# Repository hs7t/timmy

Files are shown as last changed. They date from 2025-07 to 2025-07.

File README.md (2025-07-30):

# Timmy

Timmy is a small [hackpad](https://hackpad.hackclub.com/) input device!
It features:

- a custom PCB
- two fun knobs
- 9 keys
- a pretty cool case!

## Parts

Timmy is composed of a case and two knob caps, totaling four
3D-printed pieces (the case top and bottom, a round knob, and a square knob).
It took me a bit to arrive at this design, and I'm quite fond of
it! Everything fits together using heatset inserts for 4 M3 bolts.

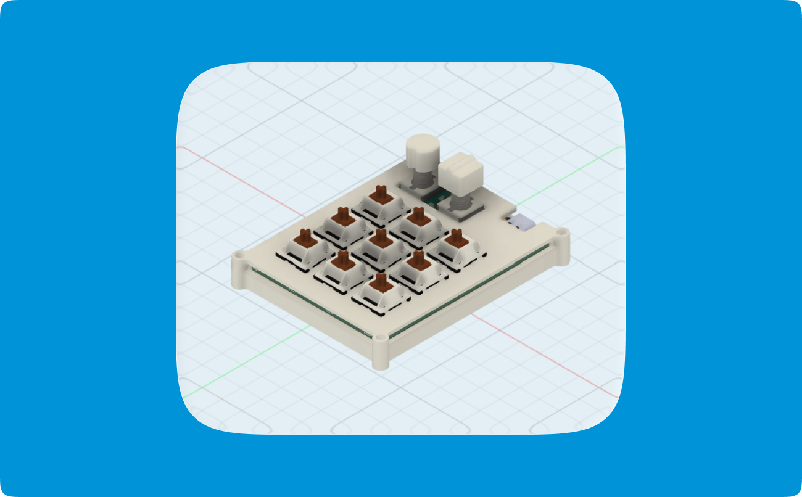
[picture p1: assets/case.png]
An angled top view of a macropad with 9 switches and two rotary encoders

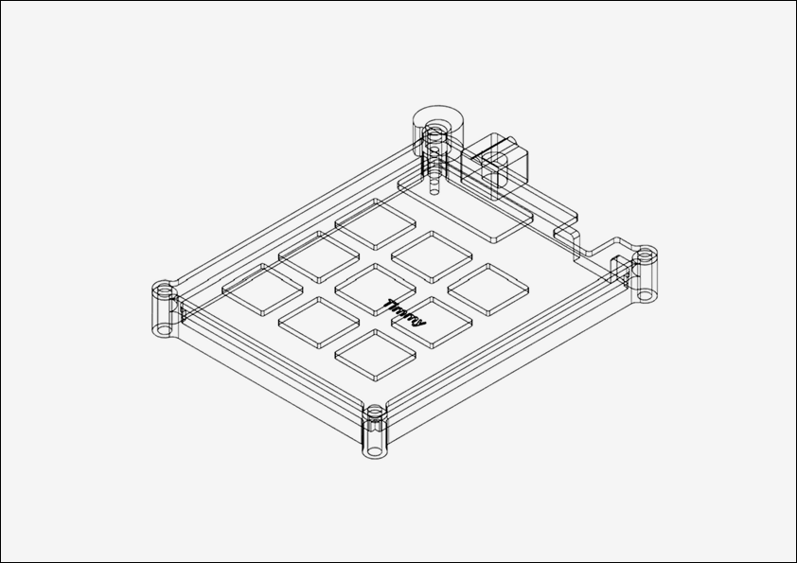
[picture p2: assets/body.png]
An angled top view of the macropad's body


## PCB

The PCB was designed in KiCAD. It's my first PCB ever, so it might
not be that great!

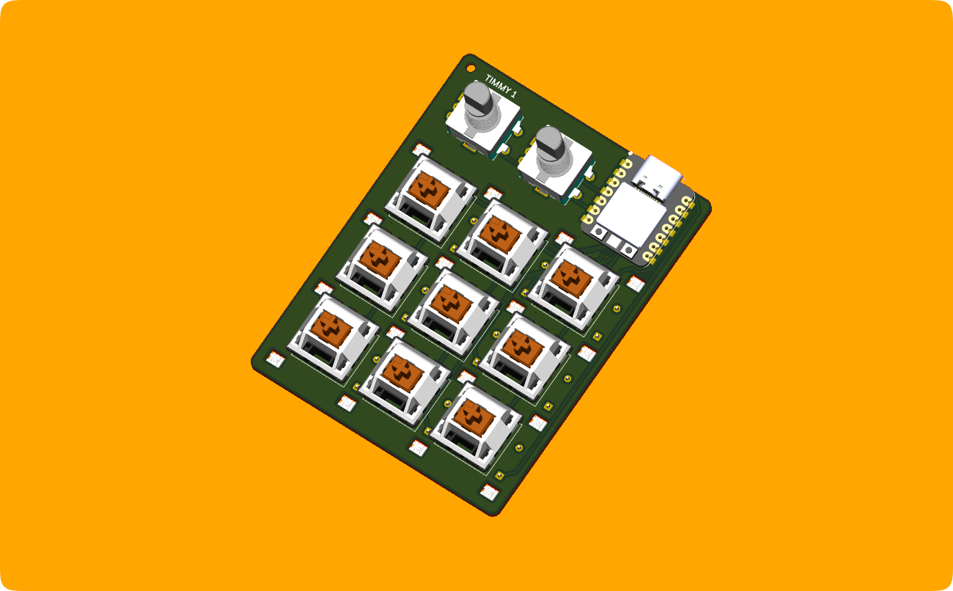
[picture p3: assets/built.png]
A render of PCB assembled with various components, including a microcontroller, two rotary encoders, and various switches

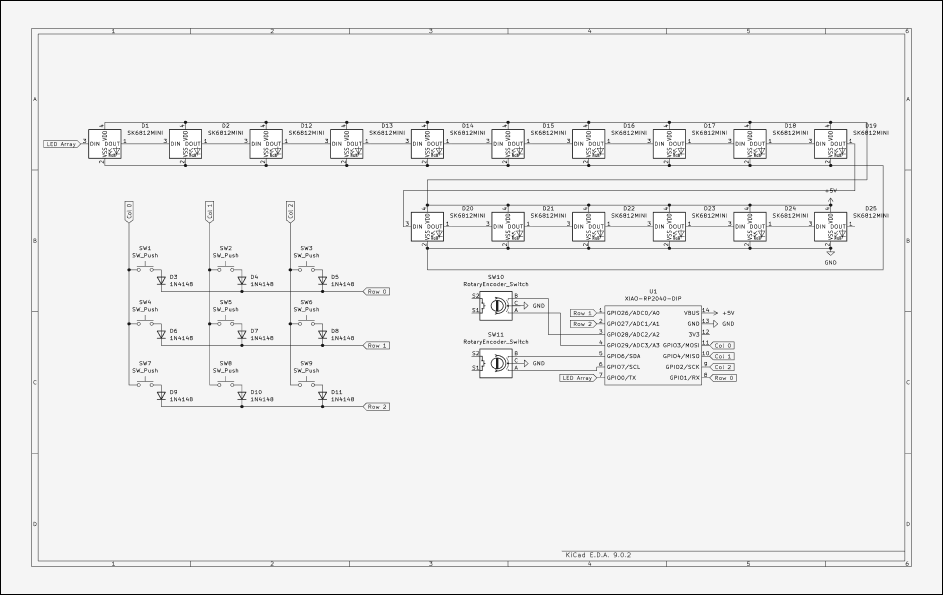
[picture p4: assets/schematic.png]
S screenshot of the schematic for the PCB


This board is double-layered and has a ground copper fill.

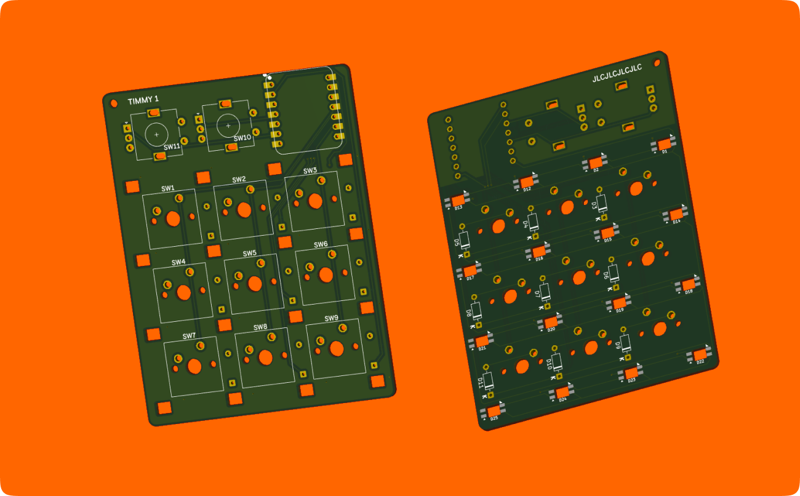
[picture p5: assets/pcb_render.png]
Renders for the PCB without components from front and behind angles

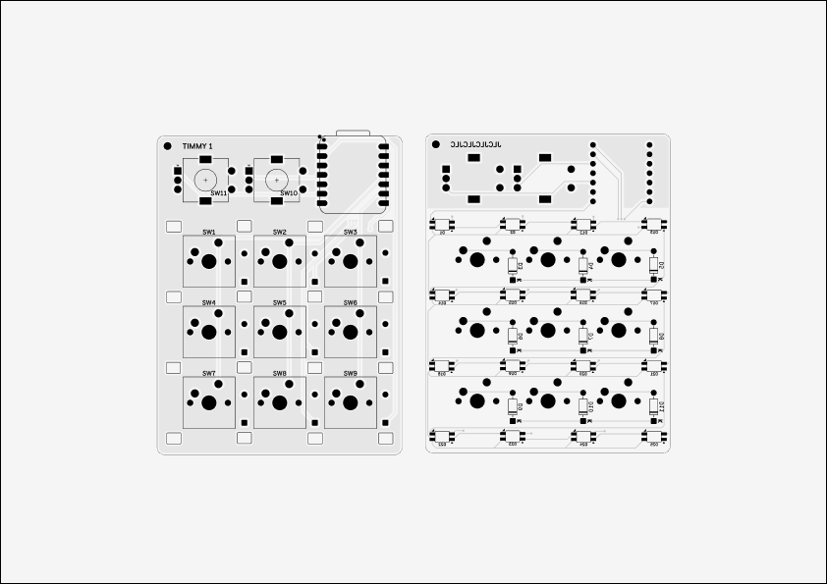
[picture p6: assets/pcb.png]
2D drawings of the PCB, front and back


## Materials

- 1 Seeed XIAO RP2040
- 9 through-hole 1N4148 Diodes
- 9 MX-Style switches
- 2 EC11 Rotary encoders
- 9 DSA keycaps
- 16 SK6812 MINI-E LEDs
- 4 M3x16mm screws
- 4 M3x5mx4mm heatset inserts
- 4 3D printed parts
- 1 double-layered PCB

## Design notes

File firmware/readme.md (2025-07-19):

# timmypad

timmypad

_A Hackpad!_

-   Keyboard Maintainer: [Haidar Alí Sinisterra Rojas](https://github.com/hs7t)
-   Hardware Supported: _The PCBs, controllers supported_
-   Hardware Availability: _Links to where you can find this hardware_

Make example for this keyboard (after setting up your build environment):

    make timmypad:default

Flashing example for this keyboard:

    make timmypad:default:flash

See the [build environment setup](https://docs.qmk.fm/#/getting_started_build_tools) and the [make instructions](https://docs.qmk.fm/#/getting_started_make_guide) for more information. Brand new to QMK? Start with our [Complete Newbs Guide](https://docs.qmk.fm/#/newbs).

## Bootloader

Enter the bootloader in 3 ways:

-   **Bootmagic reset**: Hold down the key at (0,0) in the matrix (usually the top left key or Escape) and plug in the keyboard
-   **Physical reset button**: Briefly press the button on the back of the PCB - some may have pads you must short instead
-   **Keycode in layout**: Press the key mapped to `QK_BOOT` if it is available

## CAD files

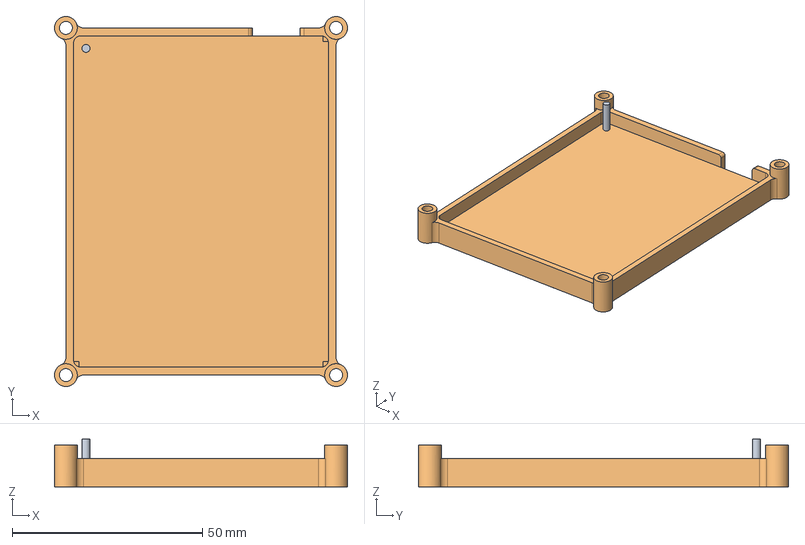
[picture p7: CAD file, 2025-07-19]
production/model-case_bottom.step
76.9 x 97.2 x 12.5 mm

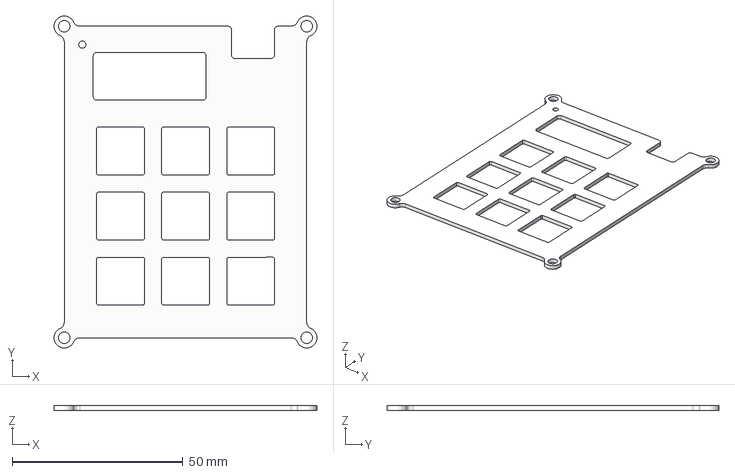
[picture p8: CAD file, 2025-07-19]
production/model-case_top.step
76.9 x 97.2 x 1.50 mm

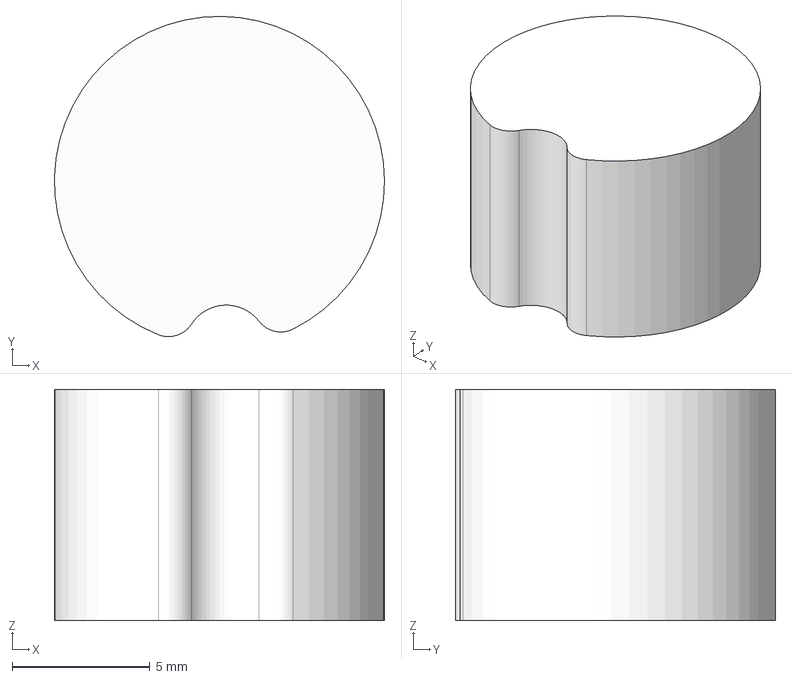
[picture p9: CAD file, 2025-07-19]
production/model-knob_circular.step
12.0 x 11.6 x 8.40 mm

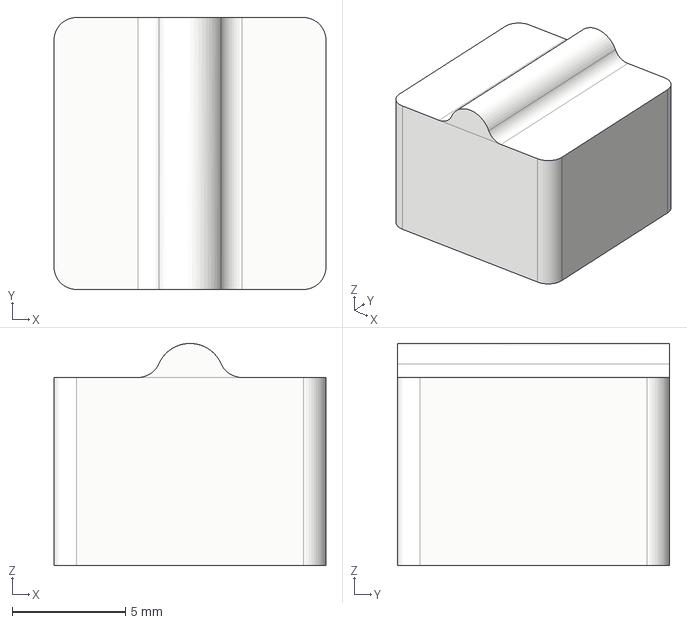
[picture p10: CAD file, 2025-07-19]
production/model-knob_precise.step
12.0 x 12.0 x 9.80 mm

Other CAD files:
cad/assembled.step

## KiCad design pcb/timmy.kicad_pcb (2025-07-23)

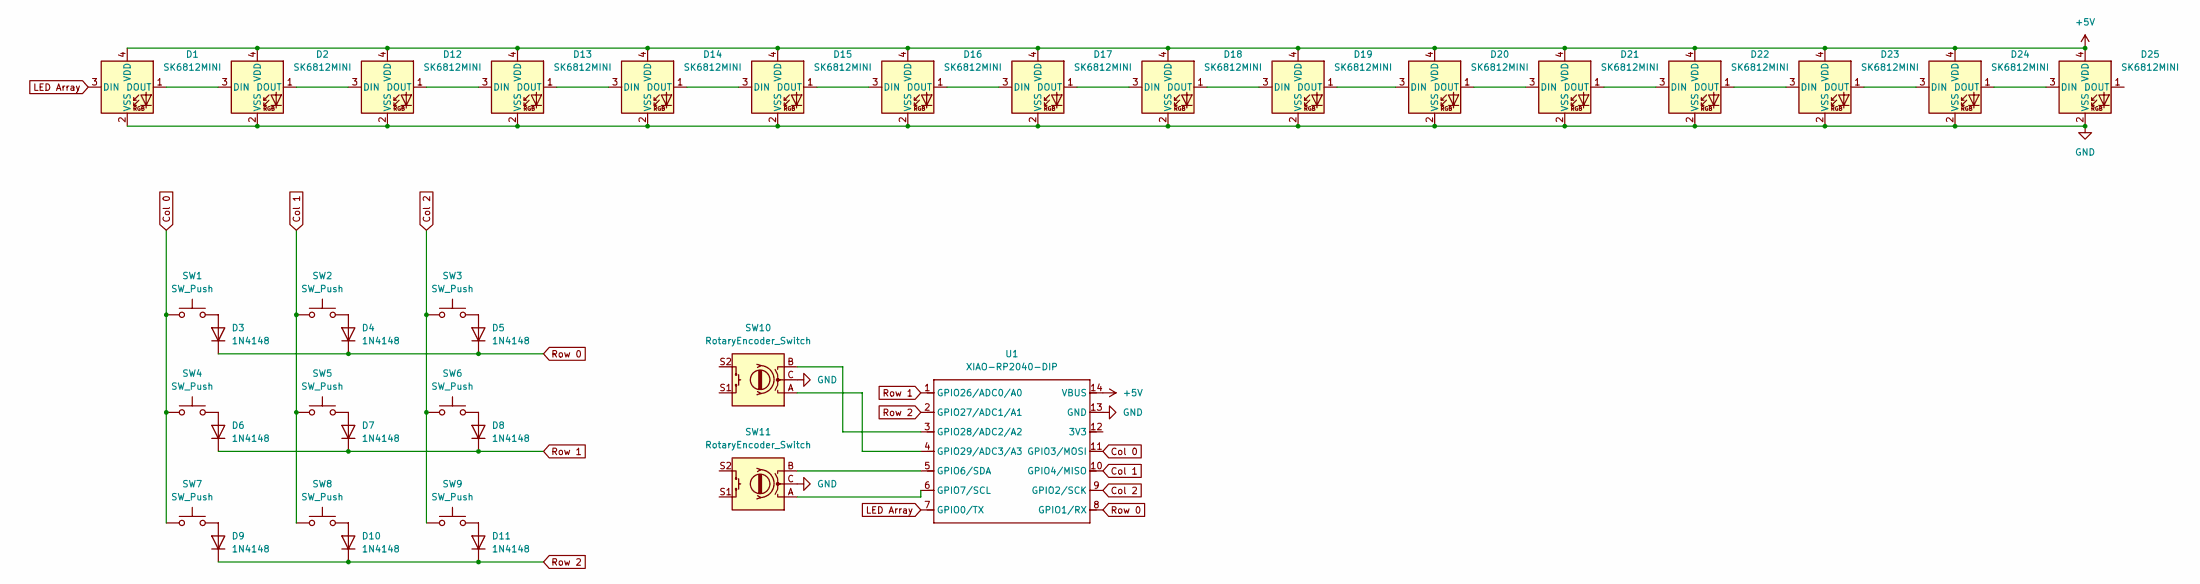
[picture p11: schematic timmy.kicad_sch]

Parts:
D1, D2, D12, D13, D14, D15, D16, D17, D18, D19, D20, D21, D22, D23, D24, D25: SK6812MINI; sk6812-mini-e
D3, D4, D5, D6, D7, D8, D9, D10, D11: 1N4148; D_DO-35_SOD27_P7.62mm_Horizontal
SW1, SW2, SW3, SW4, SW5, SW6, SW7, SW8, SW9: SW_Push; SW_Cherry_MX_1.00u_PCB
SW10, SW11: RotaryEncoder_Switch; RotaryEncoder_Alps_EC11E-Switch_Vertical_H20mm
U1: XIAO-RP2040-DIP

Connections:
+5V: D1.4 (VDD), D2.4 (VDD), D12.4 (VDD), D13.4 (VDD), D14.4 (VDD), D15.4 (VDD), D16.4 (VDD), D17.4 (VDD), D18.4 (VDD), D19.4 (VDD), D20.4 (VDD), D21.4 (VDD), D22.4 (VDD), D23.4 (VDD), D24.4 (VDD), D25.4 (VDD), U1.14 (VBUS)
Col 0: SW1.1, SW4.1, SW7.1, U1.11 (GPIO3/MOSI)
Col 1: SW2.1, SW5.1, SW8.1, U1.10 (GPIO4/MISO)
Col 2: SW3.1, SW6.1, SW9.1, U1.9 (GPIO2/SCK)
GND: D1.2 (VSS), D2.2 (VSS), D12.2 (VSS), D13.2 (VSS), D14.2 (VSS), D15.2 (VSS), D16.2 (VSS), D17.2 (VSS), D18.2 (VSS), D19.2 (VSS), D20.2 (VSS), D21.2 (VSS), D22.2 (VSS), D23.2 (VSS), D24.2 (VSS), D25.2 (VSS), SW10.C, SW11.C, U1.13 (GND)
LED Array: D1.3 (DIN), U1.7 (GPIO0/TX)
unnamed: D1.1 (DOUT), D2.3 (DIN)
unnamed: D3.2 (A), SW1.2
unnamed: D4.2 (A), SW2.2
unnamed: D5.2 (A), SW3.2
unnamed: D6.2 (A), SW4.2
unnamed: D7.2 (A), SW5.2
unnamed: D8.2 (A), SW6.2
unnamed: D9.2 (A), SW7.2
unnamed: D10.2 (A), SW8.2
unnamed: D11.2 (A), SW9.2
unnamed: D2.1 (DOUT), D12.3 (DIN)
unnamed: D12.1 (DOUT), D13.3 (DIN)
unnamed: D13.1 (DOUT), D14.3 (DIN)
unnamed: D14.1 (DOUT), D15.3 (DIN)
unnamed: D15.1 (DOUT), D16.3 (DIN)
unnamed: D16.1 (DOUT), D17.3 (DIN)
unnamed: D17.1 (DOUT), D18.3 (DIN)
unnamed: D18.1 (DOUT), D19.3 (DIN)
unnamed: D19.1 (DOUT), D20.3 (DIN)
unnamed: D20.1 (DOUT), D21.3 (DIN)
unnamed: D21.1 (DOUT), D22.3 (DIN)
unnamed: D22.1 (DOUT), D23.3 (DIN)
unnamed: D23.1 (DOUT), D24.3 (DIN)
unnamed: D24.1 (DOUT), D25.3 (DIN)
unnamed: SW11.B, U1.5 (GPIO6/SDA)
unnamed: SW11.A, U1.6 (GPIO7/SCL)
unnamed: SW10.B, U1.3 (GPIO28/ADC2/A2)
unnamed: SW10.A, U1.4 (GPIO29/ADC3/A3)
Row 0: D3.1 (K), D4.1 (K), D5.1 (K), U1.8 (GPIO1/RX)
Row 1: D6.1 (K), D7.1 (K), D8.1 (K), U1.1 (GPIO26/ADC0/A0)
Row 2: D9.1 (K), D10.1 (K), D11.1 (K), U1.2 (GPIO27/ADC1/A1)

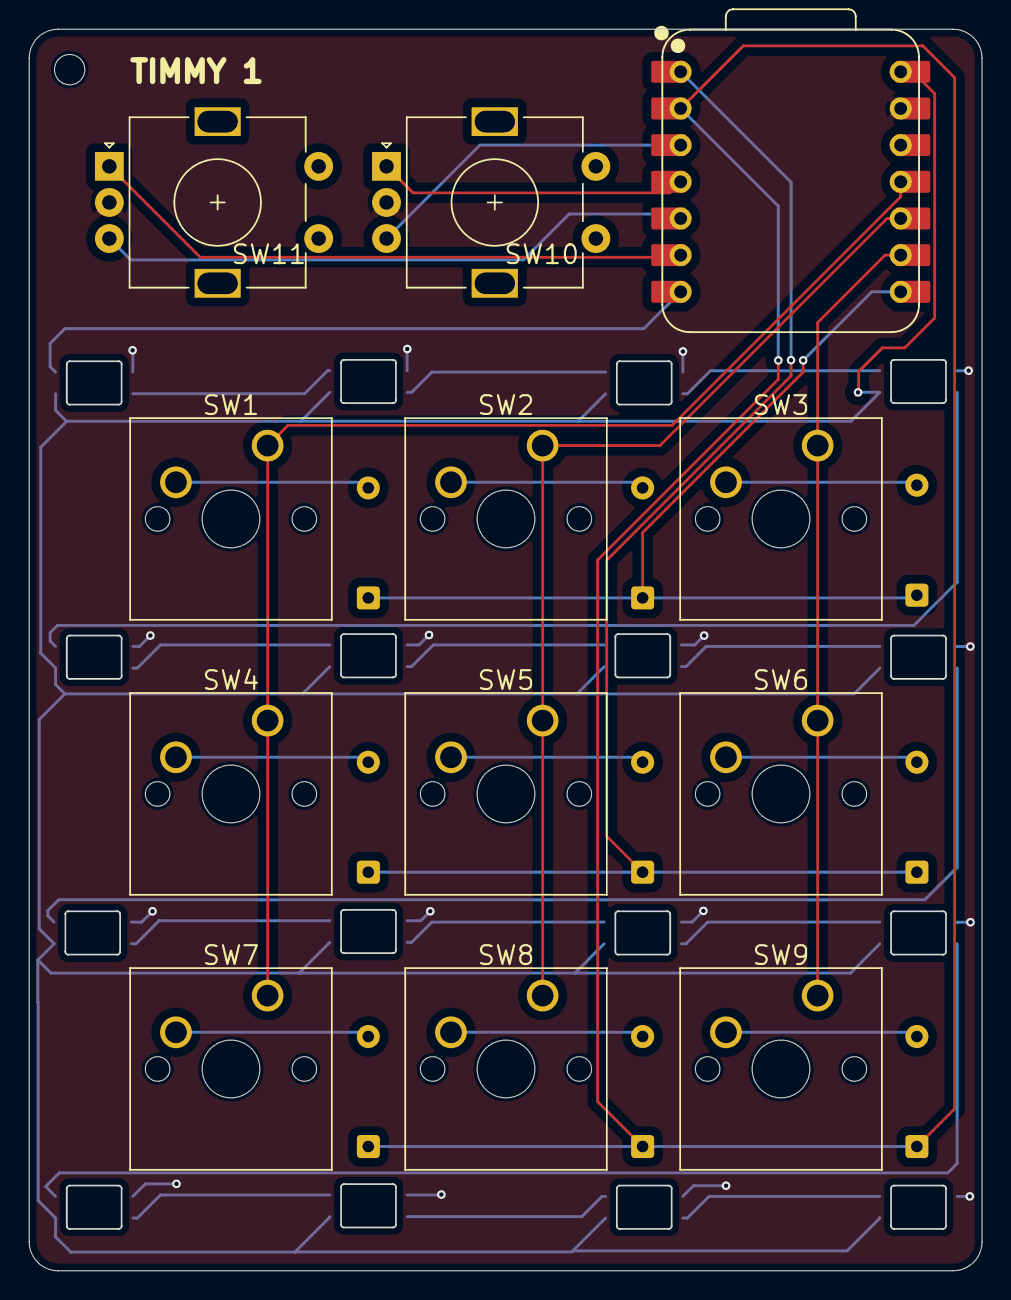
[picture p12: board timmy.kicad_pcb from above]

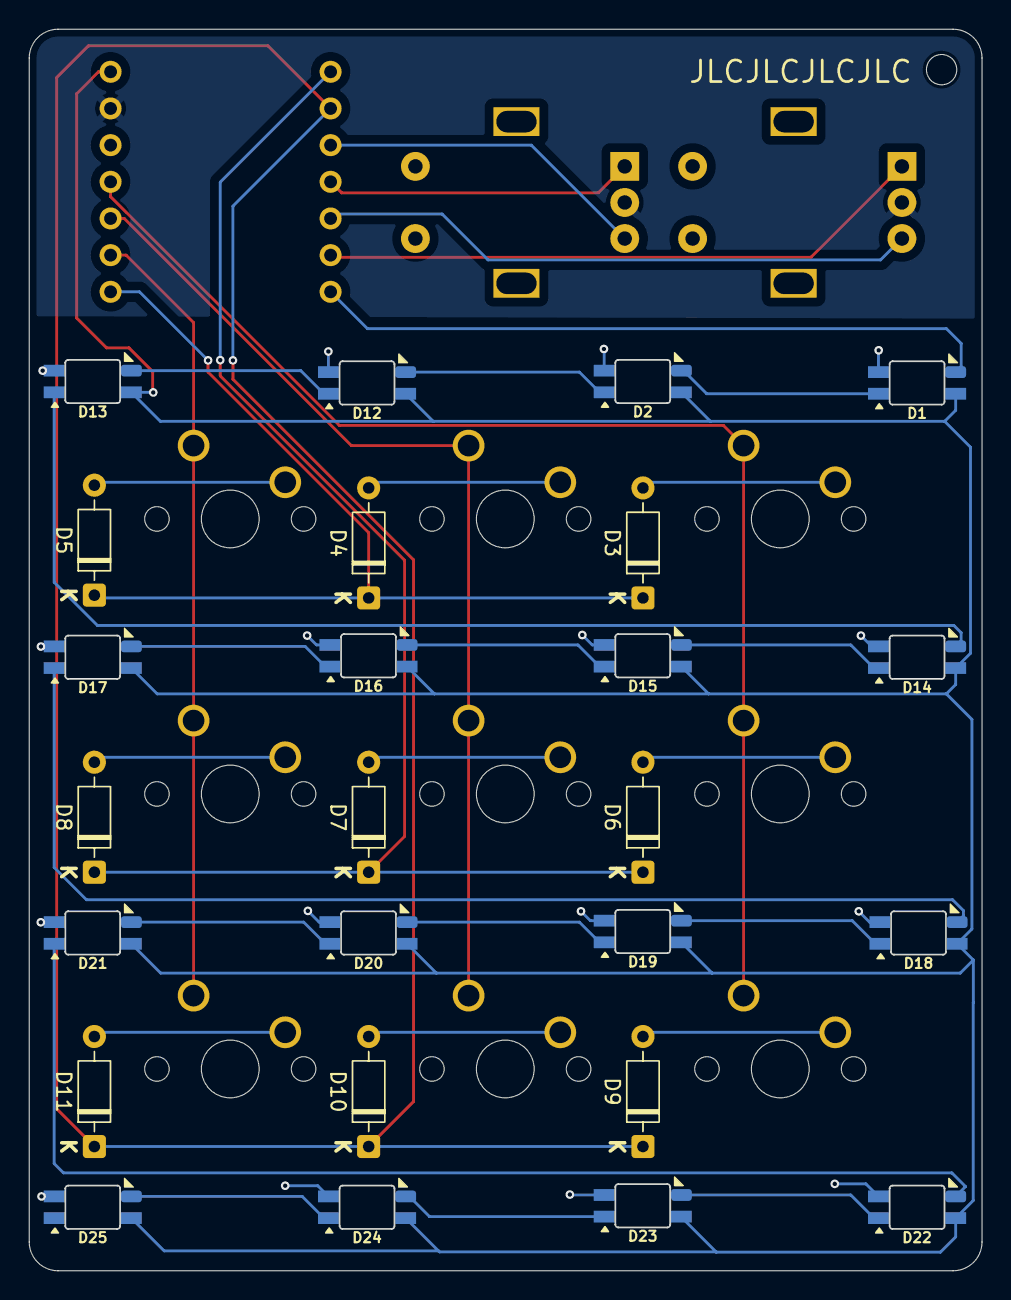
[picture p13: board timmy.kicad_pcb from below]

Board: 4 copper layers, 66.0 x 86.0 mm, 37 parts (25 on the bottom side), 37 nets.

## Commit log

2025-07-19 upload project files!
    [assembled.step, model-case_bottom.step, model-case_top.step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]
2025-07-23 update to accomodate back-mounted LEDs
    [timmy.kicad_pcb, timmy.kicad_sch]
